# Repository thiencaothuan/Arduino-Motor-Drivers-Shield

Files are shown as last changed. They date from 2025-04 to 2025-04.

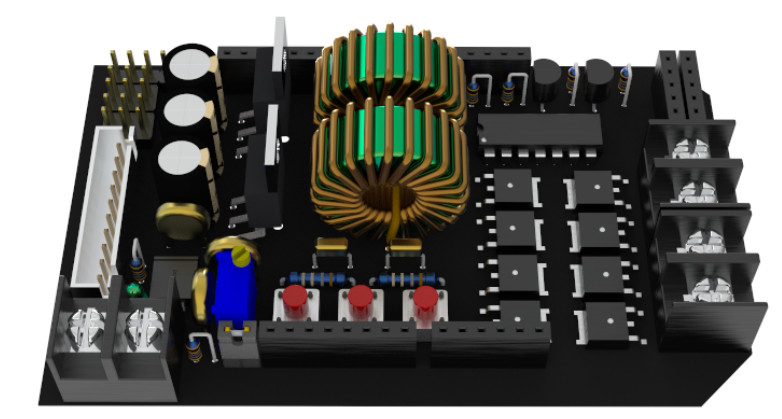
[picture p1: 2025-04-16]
Design/3d image 1.jpg

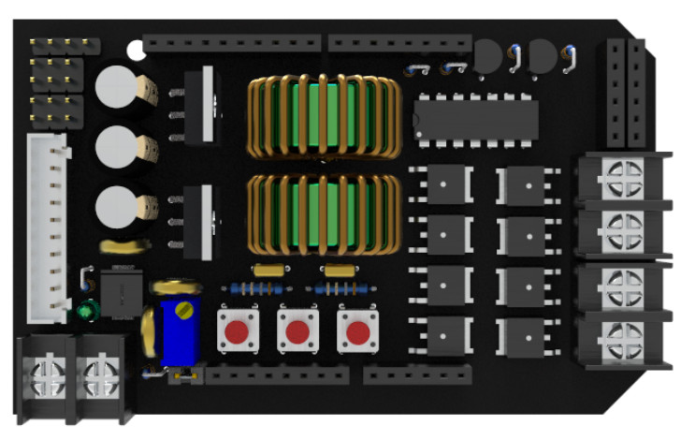
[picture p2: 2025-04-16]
Design/3d image 2.jpg

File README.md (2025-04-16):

# 🔌 2-Channel Motor Driver Shield for Arduino

A custom-designed motor driver shield supporting 2 DC motors and multiple sensor headers, made for robotics applications.

## ⚙️ Features
- Dual H-Bridge motor channels with MOSFET
- Supports 6–24V motors and servo
- Integrated voltage regulation & logic control
- Compatible with Arduino Uno R3

## 🔧 Technologies
- PCB design (Altium), MOSFET drivers
- SMD/THT soldering
- Arduino IDE code for motor test

## 🧠 My Role
- Project leader (4-member team)
- Full schematic and PCB layout
- Soldering, real-world hardware debugging

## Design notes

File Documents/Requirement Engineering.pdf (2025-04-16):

### HO CHI MINH CITY UNIVERSITY OF TECHNOLOGY

### FACULTY OF COMPUTER SCIENCE AND ENGINEERING

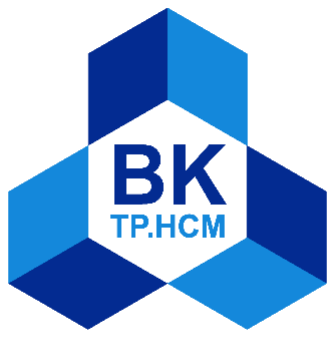
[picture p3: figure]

## ELECTRICAL ELECTRONIC CIRCUITS (CO2038)

## Practical session - Semester 231

## LAB 01 REPORT:

## Requirement Engineering

GROUP 8 – L05
GROUP ID: 2213226

Ho Chi Minh City – 2023

Member | Student ID
CAO THUẬN THIÊN | 2213226
VÕ LÊ SINH | 2212927
NGÔ MINH THÁI | 2213106
PHẠM NGỌC THẠCH | 2213175

Ho Chi Minh City University of Technology

Faculty Of Computer Science and Engineering

### 1. Create a hardware specs document

### 1.1 Plain text description

In a vehicle project, we are on the way to develop a two-wheeled vehicle that utilizes

two motors, thus we make a custom-designed circuit board that can directly connect

to the Arduino UNO R3 Microcontroller Shield. This expansion board will handle

the power supply, powering the entire vehicle by using a 3S20C battery. The circuit

board will provide two output channels used for controlling the speed and direction

of the DC motors. These output channels will be capable of adjusting the voltage

from 3V to 12V to accommodate various types of motors, with a maximum current

rating of 1.5A. The circuit will be able to interface with other modules, such as a

Bluetooth HC05 module through a plug-in connection and an 8-sensor line detector

module tracking through a cable connection. Furthermore, any unused functions and

pins of the Arduino UNO R3 will be put on the circuit board for future purposes.

Requirement

- Inclusion of suitable connectors to seamlessly connect with sensor modules,

avoiding the need for messy and unreliable wiring.

- Inclusion of built-in voltage regulation and stabilization components, eliminating

the need for external modules.

- Integration of an H-Bridge Motor Control IC to facilitate motor control.
- Integration of a 5V buzzer.
- Provision of a power switch and a reset button for convenient power control and

program reset.

- Additional connectors for other functionalities, such as Bluetooth HC05 and

servo motors.

- Capability of being compact, lightweight, and suitable for robot vehicle

construction.

### 1.2 The specs document

MAIN SPECIFICATIONS
GENERAL
Motor output
power

adjustable 3 - 12V, maximum 1.5A
Motor channels | 2
Sensor | 8-sensor line detector module, tracking through cable connectors

MECHANICAL
Weight | <100g
Width | 53.4mm
Length | 68.8mm
POWER
Battery
Battery Type | 3S20C
Battery Voltage | ~11.7 - 12.6V

Battery
Discharge
Current

20C

Input
Input Voltage | 6 - 12V
Input Current | maximum 5A
Sensor Power
Input Voltage | 3.3 - 5V
Input Current | ~100mA
Digital Signal (The same as Arduino)
HIGH | 3.3 - 5V
LOW | 0.0 - 0.8V
DC Motor Power
Output Voltage | adjustable 3 - 12V
Output Current | maximum 1.5A
| ARDUINO
Name | Arduino UNO R3
Used Power | 6 - 9V
Recommended
Power | 5V

Digital I/O
Pins | 13

Analog Input
Pins | 6
PWM Pins | 6
USB
Connector | USB.B
Main Processor | ATmega328P 16MHz
USB-Serial
Processor | ATmega16U2 16MHz
Memory | 2KB SRAM, 32KB FLASH,
| 1KB EEPROM

### 2. Hardware conceptual design

### 2.1 Find suitable connectors

The suitable connectors that we use include:

- Arduino-compatible male header pins, connecting to the Arduino board.
- Two dual connectors, connecting the two DC motors.
- A 10-pin connector, interfacing with the 8-way sensor module.

### 2.2 Sketch the form factor

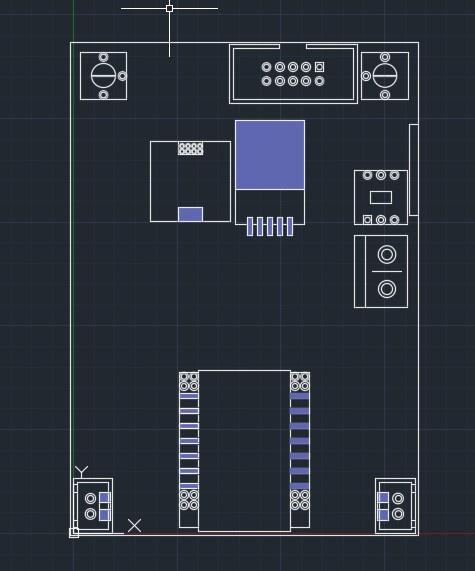
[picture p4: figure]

Figure 1: AutoCAD-sketching form factor design

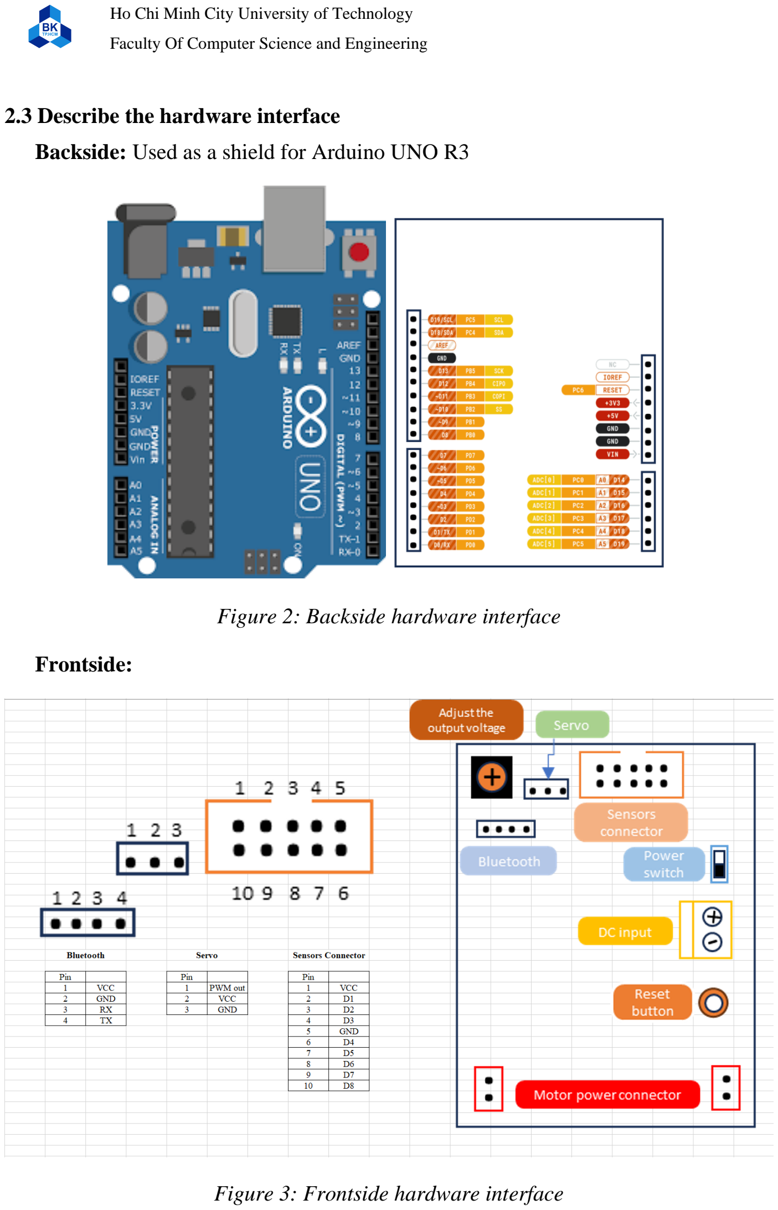
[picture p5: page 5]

### 2.3 Describe the hardware interface

Backside: Used as a shield for Arduino UNO R3

Figure 2: Backside hardware interface

Frontside:

Figure 3: Frontside hardware interface

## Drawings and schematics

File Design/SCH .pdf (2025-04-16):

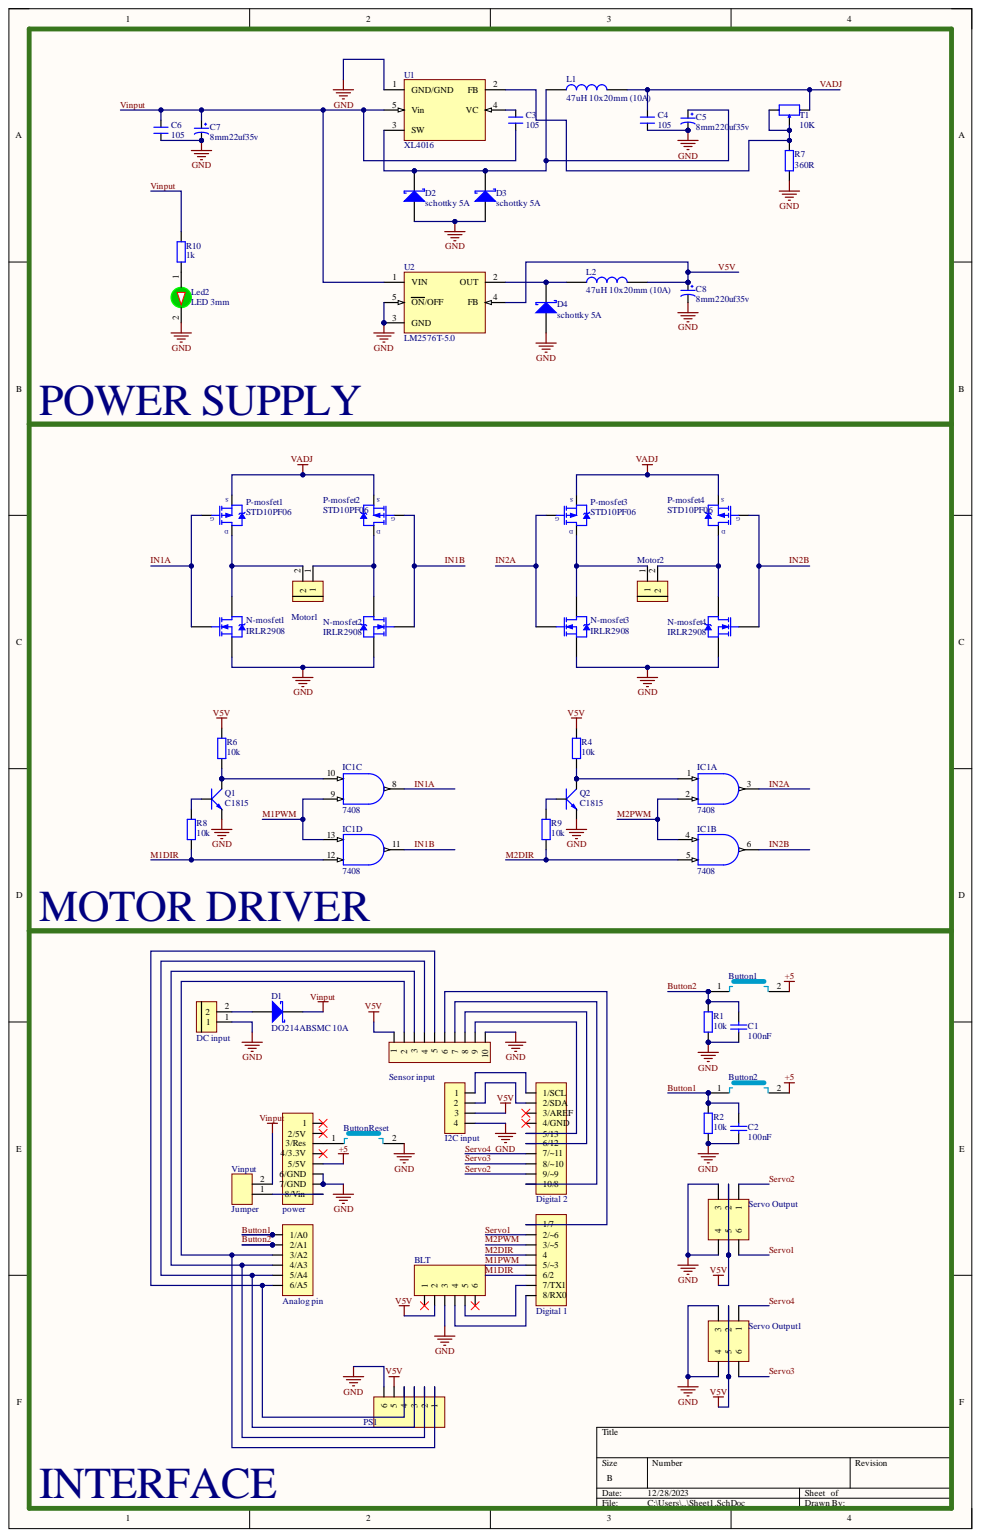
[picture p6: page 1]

5/A4 | M1DIR
6/A5

Size B | Number | Revision

Date: 12/28/2023 | Sheet of
File: C:\Users\..\Sheet1.SchDoc | Drawn By:

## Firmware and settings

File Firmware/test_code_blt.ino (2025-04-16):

#include <SoftwareSerial.h>
int M2PWM = 5;
int M2DIR = 4;
int M1PWM = 3;
int M1DIR = 2;
SoftwareSerial bt(0,1);

void move_dung(){
  digitalWrite (M1DIR, 1);
  analogWrite (M1PWM, 0);
  digitalWrite (M2DIR, 1);
  analogWrite (M2PWM, 0);
}
void move_tien(){
  digitalWrite (M1DIR, 1);
  analogWrite (M1PWM, 255);
  digitalWrite (M2DIR, 1);
  analogWrite (M2PWM, 255);
}
void move_phai(){
  digitalWrite (M1DIR, 1);
  analogWrite (M1PWM, 255);
  digitalWrite (M2DIR, 0);
  analogWrite (M2PWM, 255);
}
void move_lui(){
  digitalWrite (M1DIR, 0);
  analogWrite (M1PWM, 255);
  digitalWrite (M2DIR, 0);
  analogWrite (M2PWM, 255);
}
void move_trai(){
  digitalWrite (M1DIR, 0);
  analogWrite (M1PWM, 255);
  digitalWrite (M2DIR, 1);
  analogWrite (M2PWM, 255);
}
void setup() {
  pinMode(2, OUTPUT);
  pinMode(3, OUTPUT);
  pinMode(4, OUTPUT);
  pinMode(5, OUTPUT);
  bt.begin(9600);
  Serial.begin(9600);
  }

void loop() {
  if (bt.available())
  {
    int a = bt.read();
    Serial.println(a);
    switch(a){
      case 0:
        move_dung();
        break;
      case 1:
        move_tien();
        break;
      case 2:
        move_phai();
        break;
      case 3:
        move_lui();
        break;
      case 4:
        move_trai();
        break;
      
      }
    
}}
